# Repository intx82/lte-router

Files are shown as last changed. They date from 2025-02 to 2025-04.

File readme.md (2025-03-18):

# White box DIY LTE router

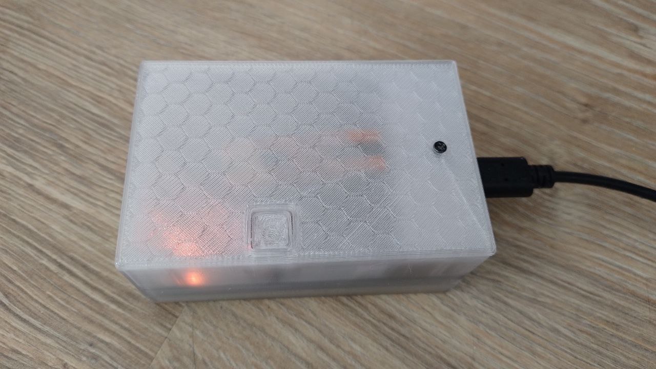
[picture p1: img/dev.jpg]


## 1. Project Description

This project provides a detailed guide to building a DIY battery-powered LTE router, designed with portability and flexibility in mind. The router features two Ethernet ports—one dedicated WAN port for external network connectivity and one LAN port to connect local devices. With built-in LTE connectivity, it ensures reliable internet access even in remote or mobile environments.

The DIY LTE router supports multiple functionalities tailored to diverse applications, such as LTE voice calls and SMS termination through VoIP, secured VPN connectivity, and integrated GPS tracking capabilities. These use cases and their configurations are explained in detail in the subsequent sections of this guide.

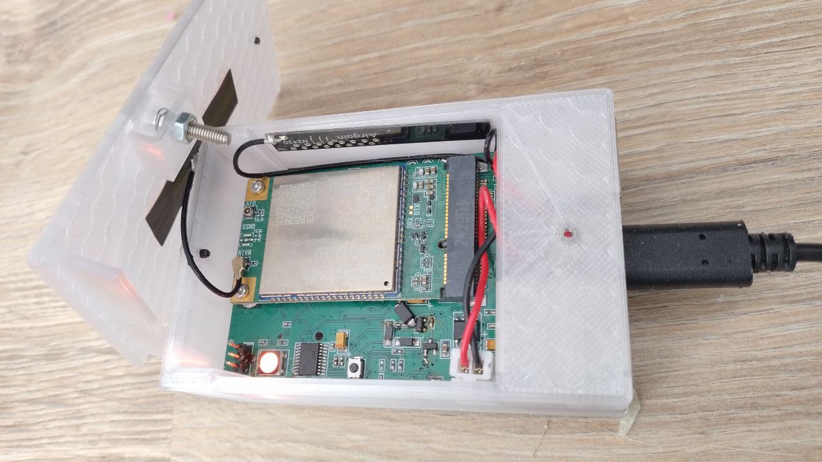
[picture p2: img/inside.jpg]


## 2. Use cases

### 2.1 LTE Voice Calls and SMS Termination via VOIP

The DIY LTE router integrates seamlessly with LTE modems (e.g., Quectel EC25) using the Asterisk VoIP server to enable voice calls and SMS functionality. Calls and SMS messages can be managed using SIP clients (e.g., Zoiper) directly over an IP network.

#### Voice Calls

- **Outgoing Calls:**
    
    - Calls initiated from the SIP client are routed through the LTE modem. The call handling logic is provided in `openwrt/extensions.conf` under the `[zoiper_in]` context.
        
    - Example:
        
        ```
        exten => _X.,1,NoOp("Outgoing call from Zoiper to EC25")
        same => n,Dial(Quectel/ec25_modem/${EXTEN},60)
        same => n,Hangup()
        ```
        
- **Incoming Calls:**
    
    - Calls received by the LTE modem are routed to the configured SIP client.
        
    - Defined in `openwrt/quectel.conf` under `[ec25_modem]` and routed through context `[from-ec25]`:
        
        ```
        exten => s,1,NoOp("Incoming call from EC25")
        same => n,Dial(PJSIP/200)
        same => n,Hangup()
        ```

#### SMS Handling

- **Outgoing SMS:**
    
    - SMS messages can be sent directly from the SIP client using SIP MESSAGE requests.
        
    - Defined under context `[outgoing-sms]`:
        
        ```
        exten => _X!,1,NoOp(Outgoing SIP MESSAGE to send as SMS)
        same => n,QuectelSendSMS(ec25_modem,${EXTEN},${MESSAGE(body)},1440,no,"magicID")
        same => n,Hangup()
        ```
        
- **Incoming SMS:**
    
    - Incoming SMS messages received by the LTE modem are forwarded to the SIP client.
        
    - Managed under `[from-ec25]`:
        
        ```
        exten => sms,1,NoOp(Inbound SMS Received)
        same => n,Set(MESSAGE(body)=${SMS})
        same => n,MessageSend(pjsip:200/200,${CALLERID(num)})
        same => n,HangUp()
        ```

#### Configuration and Permissions

- Configuration files (`extensions.conf`, `PJSIP.conf`, `quectel.conf`, and `modules.conf`) are available in the project's `openwrt` folder.
    
- A SIP client (e.g., Zoiper) should connect to the endpoint defined in `openwrt/PJSIP.conf`.
    
- Basic Asterisk configuration (`/etc/config/asterisk`):

```conf
config asterisk 'general'  
       option enabled '1'  
       option log_stderr '1'  
       option log_stdout '0'  
       option options ''
```

- **Permissions Issues:** 

If there are permission errors accessing `ttyUSB` ports, modify `/etc/init.d/asterisk` as follows: (remove flag -U from command)

```bash
#!/bin/sh /etc/rc.common  
# Copyright (C) 2014 OpenWrt.org  
  
START=99  
  
USE_PROCD=1  
  
#PROCD_DEBUG=1  
  
NAME=asterisk  
COMMAND=/usr/sbin/$NAME  
  
LOGGER="/usr/bin/logger -p daemon.err -s -t $NAME --"  
  
start_service() {  
  
 dbdir=/var/lib/asterisk/astdb  
 logdir=/var/log/asterisk  
 cdrcsvdir=$logdir/cdr-csv  
 rundir=/var/run/asterisk  
 spooldir=/var/spool/asterisk  
 varlibdir=/var/lib/asterisk  
  
 config_load $NAME  
  
 config_get_bool enabled general enabled 0  
 if [ $enabled -eq 0 ]; then  
   $LOGGER service not enabled in /etc/config/$NAME  
   return 1  
 fi  
  
 config_get_bool log_stderr general log_stderr 1  
 config_get_bool log_stdout general log_stdout 0  
  
 config_get options general options  
  
 for i in \  
   "$logdir" \  
   "$cdrcsvdir" \  
   "$rundir" \  
   "$spooldir" \  
   "$varlibdir" \  
   "$dbdir"  
 do  
   if ! [ -e "$i" ]; then  
     mkdir -m 0750 -p "$i"  
     [ -d "$i" ] && chown $NAME:$NAME "$i"  
   fi  
 done  
  
 procd_open_instance  
 procd_set_param command $COMMAND  
 procd_append_param command \  
   $options \  
   -f  
 # forward stderr to logd  
 procd_set_param stderr $log_stderr  
 # same for stdout  
 procd_set_param stdout $log_stdout  
 procd_close_instance  
  
}  
  
reload_service() {  
 procd_send_signal $NAME  
}
```

Configuration files (`extensions.conf`, `PJSIP.conf`, `quectel.conf`, `modules.conf`) are located in the project's `openwrt` folder and should copied to the `/etc/asterisk` folder on the device. 

### 2.2 Secured VPN Gateway

The DIY LTE router supports secure VPN connections using WireGuard and OpenVPN, configured via OpenWrt's command-line interface (CLI). These VPN configurations provide secure, encrypted tunnels for safe internet browsing and remote network access.

#### 2.2.1 WireGuard Setup via UCI

- WireGuard configuration (`/etc/config/network`):
    
    ```
    config interface 'wg0'
      option proto 'wireguard'
      option private_key '<private_key_here>'
      option listen_port '51820'
      list addresses '<VPN-IP>'
    
    config wireguard_wg0
      option public_key '<peer-public-key>'
      option allowed_ips '<VPN_SUBNET>'
      option endpoint '<VPN_SERVER_IP:PORT>'
    ```
    
- Firewall rules in `/etc/config/firewall`:
    
    ```
    config zone
      option name 'wg'
      list network 'wg0'
      option input 'ACCEPT'
      option output 'ACCEPT'
      option forward 'REJECT'
    ```

#### 2.2.2 OpenVPN Setup via CLI

- Place your `.ovpn` file into `/etc/openvpn/`.
    
- Edit `/etc/config/openvpn`:
    
    ```
    config openvpn 'vpnclient'
      option enabled '1'
      option config '/etc/openvpn/<your-config>.ovpn'
    ```
    
- Adjust firewall settings in `/etc/config/firewall`:
    
    ```
    config zone
      option name 'vpn'
      option input 'REJECT'
      option output 'ACCEPT'
      option forward 'REJECT'
      list network 'vpnclient'
    
    config forwarding
      option src 'lan'
      option dest 'vpn'
    ```

#### 2.2.3 LTE Modem MBIM Configuration and Routing

- Reconfigure Quectel EC25 modem to use MBIM mode:
    
    ```
    echo 'at+qcfg="usbnet",1' | socat - /dev/ttyUSB2,crlf
    ```
    
- Configure network interface in `/etc/config/network`:
    ```
    config interface 'wwan'
      option proto 'dhcp'
      option ifname 'eth1'
    ```
- Firewall configuration in `/etc/config/firewall`:
    ```
    config zone
      option name 'wwan'
      list network 'wwan'
      option input 'REJECT'
      option output 'ACCEPT'
      option forward 'REJECT'
      option masq '1'
    
    config forwarding
      option src 'lan'
      option dest 'wwan'
    ```

#### 2.2.4 Routing All Traffic through VPN via WWAN (`eth1`)

- Configure default routing to forward all traffic through VPN interface linked with the WWAN (`eth1`):
    ```
    uci set network.lan.gateway='<VPN_GATEWAY_IP>'
    uci set network.lan.dns='<VPN_DNS_IP>'
    uci commit network
    /etc/init.d/network restart
    ```
- Ensure firewall rules allow forwarding from LAN to VPN:
    ```
    config forwarding
      option src 'lan'
      option dest 'vpn'
    ```
This setup ensures that all network traffic from your local devices is securely tunneled through your VPN connection using the WWAN (`eth1`) interface.

### 2.3 Network Storage with MicroSD and NFS Server

The DIY LTE router includes onboard storage using a MicroSD card and features an integrated NFS-kernel-server for network file sharing.

#### Mounting the MicroSD Card

Use the following commands to detect and mount the MicroSD card automatically:

```
block detect | uci import fstab
uci commit
/etc/init.d/fstab enable
/etc/init.d/fstab start
```

Example UCI configuration (`/etc/config/fstab`):

```
config global
        option anon_swap '0'
        option anon_mount '0'
        option auto_swap '1'
        option auto_mount '1'
        option delay_root '5'
        option check_fs '0'

config mount
        option target '/mnt/mmcblk0p1'
        option uuid '<UUID_generated_by_block_detect>'
        option enabled '1'
```

Verify mounted storage with:

```
df -h
```

#### Configuring the NFS-kernel-server

- Configure exports in `/etc/exports`:

```
/mnt/mmcblk0p1  *(rw,sync,no_root_squash,no_subtree_check)
```

- Enable and start NFS server:

```
/etc/init.d/nfsd enable
/etc/init.d/nfsd start
```

- Adjust firewall rules to allow NFS:

```
uci add firewall rule
uci set firewall.@rule[-1].src='lan'
uci set firewall.@rule[-1].dest_port='2049'
uci set firewall.@rule[-1].proto='tcpudp'
uci set firewall.@rule[-1].target='ACCEPT'
uci commit firewall
/etc/init.d/firewall restart
```

This setup allows your router to function as a robust network-attached storage solution accessible to clients on your local network.

## 3. Assembly

### 3.1 Hardware

#### 3.1.1 STL files and box

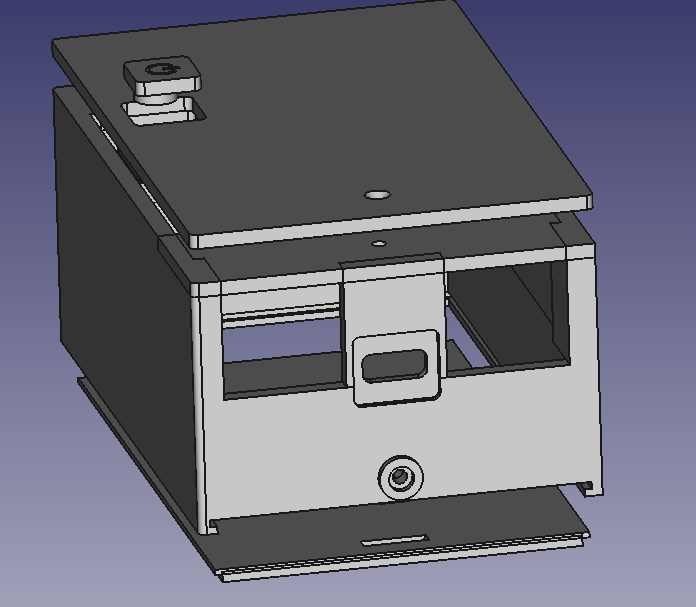
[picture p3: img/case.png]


use files located in `3d/stl`. To modify it, use 'Freecad'

#### 3.1.2 PCB

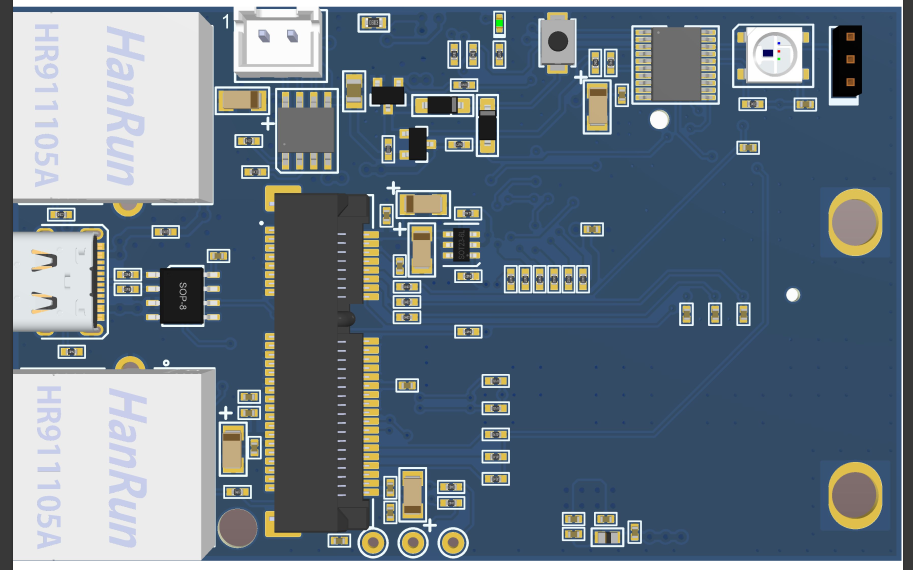
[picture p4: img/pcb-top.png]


Use altium project `pcb/lte-router_V3_ARCHIVE/lte-router_V3_DIV/lte-router_V3.PrjPcb`

Schematic and PCB documentation available in PDF file here: [`pcb/lte-router_V3_ARCHIVE/lte-router_V3_GENERATED/DOC/lte-router_V3_DOC.PDF`](https://github.com/intx82/lte-router/blob/master/pcb/lte-router_V3_ARCHIVE/lte-router_V3_GENERATED/DOC/lte-router_V3_DOC.PDF)

**Additional thanks to Michael who done this work**

### 3.2 Software

#### 3.2.1 Power Managment IC (pmic) firmware

For `PMIC` has been used 'CH32V003F4P6' Risc-V CPU

To build it, be sure that you have installed `riscv64-gnu-linux-gcc` and just run `make -C pmic/fw`.

#### 3.2.2 Openwrt 

- Use official 'Openwrt' repository and checkout to the '09e32bf62a7dc0f252605720910b02ed26994263' commit, follow the openwrt build instructions
- Then put `openwrt/config` file to the openwrt folder as .config
- After copy contents of `pmic/tool` to the `package/utils/pmicctrl/`
- Apply all patches from `openwrt` folder
- `make`
- Take a firmware from `bin/targets/ramips/mt76x8` 
- Upload it to the device using `scp` - `scp openwrt-snapshot-r28739+2-69890e16b3-ramips-mt76x8-hilink_hlk-7688a-squashfs-sysupgrade.bin root@192.168.1.1:/tmp` or if this is stock HLK-7688 - `scp openwrt-snapshot-r28466-6881b48dc6-ramips-mt76x8-hilink_hlk-7688a-squashfs-sysupgrade.bin root@192.168.16.254:/tmp`. Password to stock module Wi-Fi is '12345678'
- Flash it with `sysupgrade -n /tmp/openwrt-snapshot-r28739+2-69890e16b3-ramips-mt76x8-hilink_hlk-7688a-squashfs-sysupgrade.bin`

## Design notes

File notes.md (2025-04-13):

## GDB CH32V003

```
set architecture riscv:rv32
target extended-remote /dev/ttyACM0
load main.elf 0
```

## tasks V1->V2

- [x] C6 to 0603 or type-a tantal
- [x] c18 - 0402
- [x] vt3 (ap2301b) wrong case, sot23-6 instead of sot23-3
- [x] power switch latch change to ch32v003
	- [x] PD3 - enable (to base vt2)
	- [x] PD4 - button
	- [x] PC1 - I2C-SDA (25 pin hlk-7688)
	- [x] PC2 - I2C-SCL (24 pin hlk-7688)
	- [x] PA2 - voltage divider 470k/470k to battery (before tp4056)
	- [x] PC6 - WS2812
	- [x] PD1 - SWD (SWIO)
	- [x] wwan/wpan/wlan led - to one pin
	- [x] power tp4056 - one pin
	- [x] charge tp4056 - one pin
- [x] sim card set connector with loading from top, not from side
- [x] add 10k pull-up for sd-card (@see link-it 7688 schematic)
- [x] add zero resistor to avoid dw01

## Notes

```
socat /dev/ttyUSB2,b115200,raw,echo=0,crnl -

```

# Asterisks termination 
## quectel.conf

```
[general]  

[ec25_modem]  
device=/dev/ttyUSB1      ; or whichever your voice port is  
context=from-ec25        ; context for incoming calls from EC25  
audio=/dev/ttyUSB1       ; in some builds you might configure separate audio channels  
data=/dev/ttyUSB2        ; optional if used for data  
autostart=yes  
```

## PJSIP.conf

```
[transport-udp]  
type=transport  
protocol=udp  
bind=0.0.0.0  

[200]  
type=endpoint  
transport=transport-udp  
context=zoiper_in  
disallow=all  
allow=ulaw  
auth=200  
aors=200  
message_context=outgoing-sms  
  
[200]  
type=auth  
auth_type=userpass  
username=200  
password=200  
  
[200]  
type=aor  
max_contacts=1  
```

## extension.conf

```
[zoiper_in]  
; When Zoiper dials an external number, send it out through the EC25  
exten => _X.,1,NoOp("Outgoing call from Zoiper to EC25")  
same => n,Dial(Quectel/ec25_modem/${EXTEN},60)  
same => n,Hangup()  
  
[outgoing-sms]  
exten => _X!,1,NoOp(Outgoing SIP MESSAGE to send as SMS)  
same => n,Verbose(1,"Outbound SMS to: ${EXTEN} -> ${MESSAGE(body)}")  
same => n,QuectelSendSMS(ec25_modem,${EXTEN},${MESSAGE(body)},1440,no,"magicID")  
same => n,NoOp("SMS send status: ${QUECTELSENDSMS_STATUS}")  
same => n,Hangup()  
  
[from-ec25]  
; For calls that come in from the modem  
exten => s,1,NoOp("Incoming call from EC25")  
same => n,Verbose(2, "Incoming dial ${CALLERID(num)})  
same => n,Dial(PJSIP/200)  
same => n,Hangup()  
  
exten => sms,1,NoOp(Inbound SMS Received)  
same => n,Set(MESSAGE(body)=${SMS})  
same => n,Set(MESSAGE(from)=sip:${CALLERID(num)}@domain.invalid)  
same => n,Set(MESSAGE(to)=sip:200@domain.invalid)    
same => n,MessageSend(pjsip:200/200,${CALLERID(num)})  
same => n,Verbose(2, "Send status is ${SMS} ${CALLERID(num)})  
same => n,HangUp()
```

### modules.conf

root@OpenWrt:~# cat /etc/asterisk/modules.conf    
```
[modules]  
autoload=yes  
  
noload = chan_alsa.so  
noload = res_hep.so  
noload = res_hep_pjsip.so  
noload = res_hep_rtcp.so  
noload = chan_sip.so  
noload = app_voicemail_imap.so  
noload = app_voicemail_odbc.so  
  
load => chan_quectel.so
```

----

# PMIC register map

| # | type | name | Description |
| --- | --- | --- | --- |
| 4..7 | uint32 | tm | Internal time in ms |
| 8..11  | uint32 | led-color | Led Color GRB,  if data\[11\] > 0 then update_led() |
| 12..13 | uint16 | adc-val | Battery value |
| 14 | uint8  | in-state  | Bits:<br>0 - TP4056 - Charge<br>1 - TP4056 - Standby<br>2 - LTE leds state (wwan/wpan/wlan)<br>3 - Power button state<br>4 - Battery low indication (~3.5v) |
| 31 | uint8  | shutdown  | if write 0xff -> then shutdown |

----------

# I2C shortcuts

```
i2cdetect -y 0 # PMIC should be visible as device with address 9
i2cget -y 0 9 0 i 32 # get all pmic registers

i2cset -y 0 9 8 0xff b # set red led to 0xff
i2cset -y 0 9 11 0xff b # apply led color

i2cset -y 0 9 8 0x10 0x20 0x30 0x01 i  # update the color of the led in one command
i2cset -y 0 9 8 0x0 0x0 0x0 0x01 i  # update the color of the led in one command

i2cset -y 0 9 31 0xff b  # shutdown the device
```

-----

# Wireless config

```
config wifi-device 'radio0'      
       option type 'mac80211'  
       option path 'platform/10300000.wmac'  
       option band '2g'     
       option channel '1'  
       option htmode 'HT20'  
       option disabled '0'  
  
config wifi-iface 'default_radio0'  
       option device 'radio0'  
       option network 'lan'  
       option mode 'ap'  
       option ssid 'OpenWrt'  
       option encryption 'none'
```

For WPA encryption change `config wifi-iface 'default_radio0'` to:

```
config wifi-iface 'default_radio0'
        option device 'radio0'
        option network 'lan'
        option mode 'ap'
        option ssid '[access-point]'
        option encryption 'psk2'
        option key '[das-password]'
```

# Control LTE module power

```
echo 'out' > /sys/class/gpio/lte_sw/direction
echo 1 > /sys/class/gpio/lte_sw/value # enable
echo 0 > /sys/class/gpio/lte_sw/value # disable
```

## EC200 workaround

To set right modem mode to use it as WWAN:

```
echo "at+qnetdevctl=3,1,1" | socat - /dev/ttyUSB2,crlf
```

# PMICCTRL UBUS  shortcuts

```bash
ubus listen
ubus call pmic set_led '{"r":128, "g":0, "b": 16}'
ubus call pmic shutdown
```

## BlockD

To mount flash use next thing:

```bash
block detect | uci import fstab
uci commit
```

## Enable wifi

```
uci set wireless.radio0.disabled=0
```

## Change EC25 USB mode

```
at+qcfg="usbnet",1
```

/etc/config/network

```
config interface 'wwan'  
       option proto 'dhcp'  
       option ifname 'eth1'
```

## PCB V2->V3

- [x] Ethernet led connect to VCC instead of GND
- [x] Connect modem thru the diode to the VBAT (after Mosfet)
- [x] Change bc847 to bss138 and add to the Gate-GND resistor 100k
- [x] separate resistors to CC1 / CC2  (for each pin own - 5.1k)

## Wireguard config

/etc/config/firewall:

```
  
config zone  
       option name 'wg'  
       list network 'wg0'  
       option input 'ACCEPT'  
       option output 'ACCEPT'  
       option forward 'REJECT'  
  
config rule  
       option name 'Allow-SSH-from-WG'  
       option src 'wg'  
       option target 'ACCEPT'  
       option dest_port '22'  
       option proto 'tcp'  
  
config rule  
       option name             Allow-asterisk  
       option src              'wg'  
       option proto            udp  
       option dest_port        5060  
       option target           ACCEPT  
       option family           ipv4
```

/etc/config/network

```
config interface 'wg0'  
       option proto 'wireguard'  
       option private_key 'BASE64='  
       option listen_port '51820'  
       list addresses 'VPN-IP'  
  
config wireguard_wg0  
       option public_key 'BASE64='  
       option allowed_ips 'VPN-SUBNET/24'  
       option endpoint_host 'SRV-IP'  
       option endpoint_port 'SRV-PORT'  
       option persistent_keepalive '25'
```

## Traffic count

`AT+QGDCNT?`  - Packet Data Counter
`AT+QNWINFO` - Information about network

# Internet over SLIP

device:

```plantuml
device@10.42.0.2 -> host@10.42.0.1
```

Device sl0.up script:

```bash
#!/bin/sh  
  
stty -F /dev/ttyS0 -crtscts speed 230400  
sleep 1  
slattach -L /dev/ttyS0 &  
sleep 1  
ifconfig sl0 10.42.0.2 pointopoint 10.42.0.1 up  
ifconfig sl0 mtu 1536 up  
# route add default gw 10.42.0.1
```

Host sl0.up script:

```bash
#!/bin/bash  
  
stty -F /dev/ttyUSB0 speed 230400 -crtscts  
slattach -L -d /dev/ttyUSB0  &  
sleep 1  
ifconfig sl0 10.42.0.1 pointtopoint 10.42.0.2 up  
ifconfig sl0 mtu 1536 up  
route add default gw 10.42.0.2  # Use this if you planned to share internet throught SLIP interface
```

Check files `host.sl0.up` `dev.sl0.up` in openwrt folder
If you planned to share internet connection throught SLIP, then add exceptions to the firewall:

`/etc/config/firewall`: ('+' - means added)
```
config zone  
       option name             lan  
       list   network          'lan'  
+       list   network          'slip'  
       option input            ACCEPT  
       option output           ACCEPT  
       option forward          ACCEPT  
  
config zone  
       option name             wan  
       list   network          'wan'  
       list   network          'wan6'  
+       list   network          'wwan'  
       option input            REJECT  
       option output           ACCEPT  
       option forward          REJECT  
       option masq             1  
       option mtu_fix          1
```

`/etc/config/network`:

```
config device  
       option name 'sl0'  
  
config interface 'slip'  
       option device 'sl0'

config interface 'wwan'  
       option proto 'dhcp'  
       option ifname 'eth1'
```

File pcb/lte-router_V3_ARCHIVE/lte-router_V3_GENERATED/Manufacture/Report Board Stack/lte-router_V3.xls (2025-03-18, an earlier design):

Board Stack Report
Stack Up |  | Layer Stack
Layer | Board Layer Stack | Name | Material | Thickness | Constant
1 |  | Top Paste
2 |  | Top Overlay
3 |  | Top Solder | Solder Resist | 0.010mm | 3.5
4 |  | Top Layer | Copper | 0.036mm
5 |  | Dielectric1 | FR-4 | 0.550mm | 4.2
6 |  | Inner Layer 2 | Copper | 0.036mm
7 |  | Dielectric 4 |  | 0.200mm | 4.2
8 |  | Inner Layer 3 | Copper | 0.036mm
9 |  | Dielectric2 | FR-4 | 0.550mm | 4.2
10 |  | Bottom Layer | Copper | 0.036mm
11 |  | Bottom Solder | Solder Resist | 0.010mm | 3.5
12 |  | Bottom Overlay
13 |  | Bottom Paste
 | Height : 1.463mm

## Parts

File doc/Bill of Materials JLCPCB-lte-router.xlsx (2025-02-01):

Description | Designator | Footprint | JLCPCB Part #（optional）
Battery Holder (Open) 18650 1 Cell SMD (SMT) Tab | BAT1 | 1042P | C6038009
CAP CER 10nF ±10% 50V X7R 0402 | C1, C11 | C_0402 | C15195
CAP TANT 10UF 10% 16V 1206 | C2, C3, C7, C10, C14 | TANT_CAP_A | C110055
CAP CER 10PF ±5% 50V C0G/NP0 0402 | C4, C5, C12, C13, C22, C23, C24, C26 | C_0402 | C76946
CAP CER 1UF ±10% 25V X7R 0603 | C6 | C_0603 | C29936
CAP CER 4.7UF ±10% 10V X7R 0603 | C8, C20, C21 | C_0402 | C913474
CAP CER 10UF ±10% 10V X6S 0603 | C9, C15, C17 | C_0402 | C385036
CAP CER 47PF ±5% 50V C0G/NP0 0402 | C16 | C_0402 | C84706
CAP CER 10nF ±10% 50V X7R 0603 | C18, C19, C25 | C_0603 | C1589
5A 1 Horizontal attachment 6P Female -25℃~+85℃ Type-C SMD USB Connectors ROHS | J1 | USB-TYPE-C-006 | C2927026
RJ45Receptacle 1 WithLED Plugin Ethernet Connectors / Modular Connectors (RJ45 RJ11) ROHS | J2, J3 | HR911105A | C12074
-20℃~+85℃ 1.6mm Gold Card Slot MicroSD card (TF card) Flip type SMD SD Card / Memory Card Connector ROHS | J4 | TF-014-H16 | C2874208
Jamper 2 pin | JP1, JP2 | JUMP_2 | C2931354
Kontrol Point c2.0mm_h1.0mm | KP1, KP2 | KP_c2_h1
3.6A 1.5uH ±20% 5.3A SMD,4x4mm Power Inductors ROHS | L1 | SMD4x4 | C167867
FERRITE BEAD 220 OHM 0603 1LN | L2 | L_0603 | C113025
LED GREEN CLEAR 2SMD | LED1, LED3, LED5 | LED_0402_G | C2852592
LED RED CLEAR CHIP SMD | LED2, LED4 | LED_0402_R | C2852592
LED YELLOW CLEAR CHIP SMD | LED6 | LED_0402_Y | C5875733
Any Res 1206 | R1 | R_1206
RES 100K OHM 1% 1/16W 0402 | R2, R7, R12, R13, R22 | R_0402 | C60490
RES 10K OHM 1% 1/16W 0402 | R3, R8 | R_0402 | C60490
Any Res 0603 | R4, R5, R6 | R_0603
RES 1M OHM 5% 1/16W 0402 | R9 | R_0402 | C384387
RES 330 OHM 5% 1/16W 0402 | R10, R18, R19, R20 | R_0402 | C168264
RES 1K OHM 1% 1/16W 0402 | R11, R14 | R_0402 | C163815
RES 47 OHM 5% 1/16W 0402 | R15, R16, R17 | R_0402 | C170414
RES 453K OHM 1% 1/16W 0402 | R21 | R_0402 | C137978
RES 0 OHM JUMPER 1/16W 0402 | R23, R24, R25, R26, R27 | R_0402 | C60485
Plug-in Card Slot MiniSIM card SMD SIM Card Connectors ROHS | SIM1 | HYC90-SIM06-180 | C645506
SWITCH TACTILE SPST-NO 0.02A 15V | SW1, SW2 | PTS525 | C221856
SOP-8 USB2.0 Converter ROHS | U1 | SOP-8 | C2977777
4V~6V Li-Ion/Polymer 1 1A ESOP-8 Battery Management | U2 | ESOP-8 | C382139
Step-down type 2A 2.7V~5.5V SOT-23-5 DC-DC Converters ROHS | U3 | SOT-23-5 | C78988
DIODE SCHOTTKY 60V 3A SMA | VD1 | SMA | C3014012
TRANS NPN 45V 0.1A SOT23-3 | VT1, VT4 | SOT-23-3 | C94393
20V 2A 130mΩ@4.5V,2A 750mW 950mV@250uA 1 Piece P-Channel SOT-23 MOSFETs ROHS | VT2 | SOT-23-6 | C2763847
20V 3A 23mΩ@4.5V,3A 800mW 750mV@250uA 1PCSNChannel+1PCSPChannel SOT-23-6 MOSFETs ROHS | VT3 | SOT-23-6L | C2849575
CONN PCI EXP MIN FML 52POS 0.031 | X1 | 17758382 | C91936
20dBm MT7688AN Chip WiFi Modules | X2 | 7688A | C209919

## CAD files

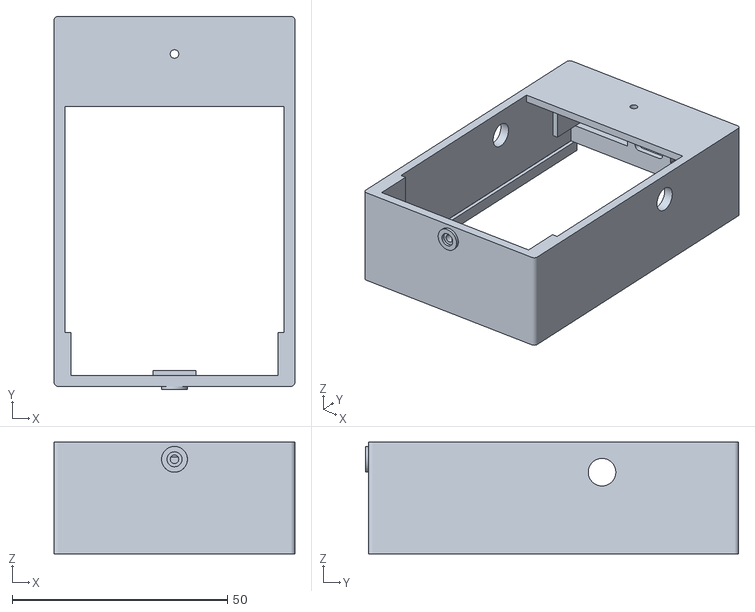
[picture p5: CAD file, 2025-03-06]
3d/stl/lte-router-main-sma.stl
56.0 x 86.8 x 26.0

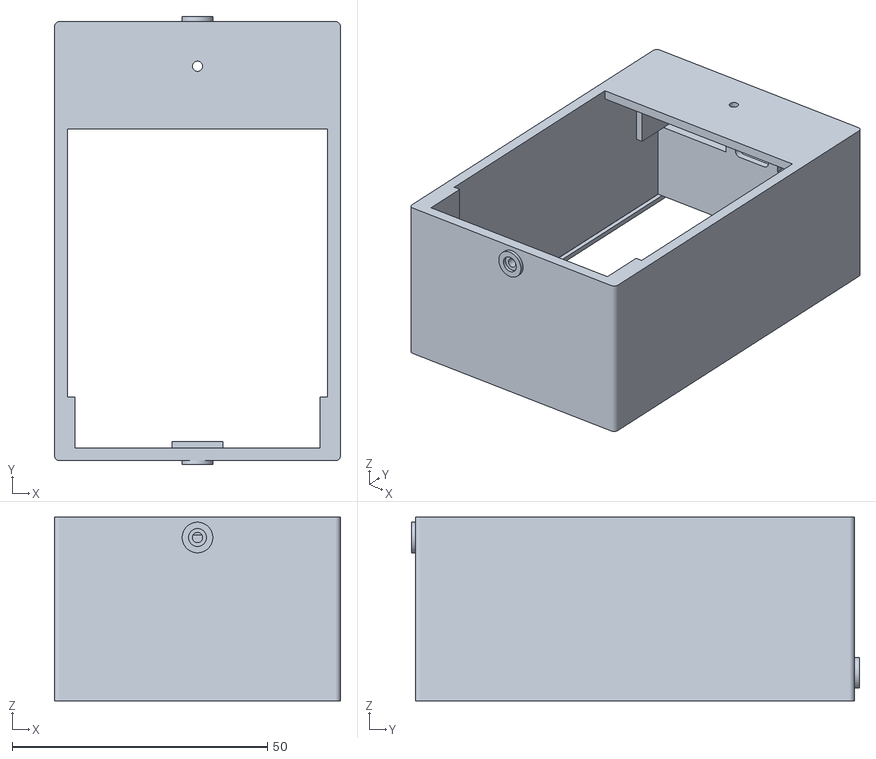
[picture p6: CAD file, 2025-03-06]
3d/stl/lte-router-table-v2-main.stl
56.0 x 87.8 x 36.0

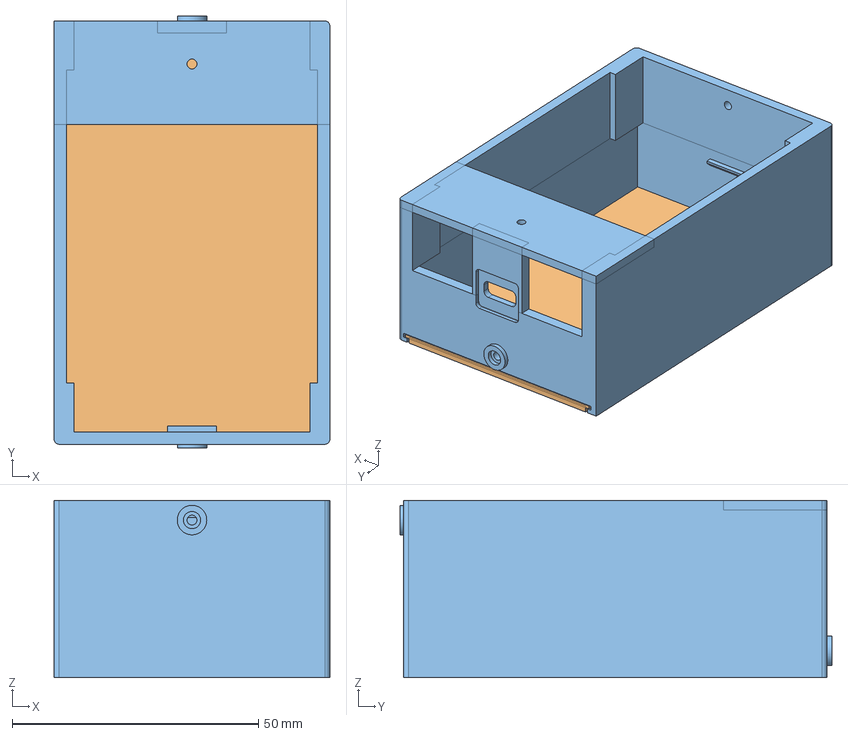
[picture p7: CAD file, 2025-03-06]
3d/lte-router-table-v2.FCStd
56.0 x 87.8 x 36.0 mm
lock
bottom
main

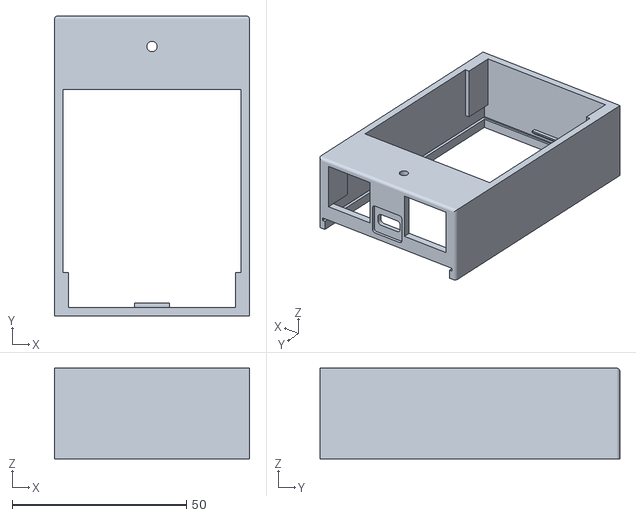
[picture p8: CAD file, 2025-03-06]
3d/stl/lte-router-table-Fillet.stl
56.0 x 86.0 x 26.0

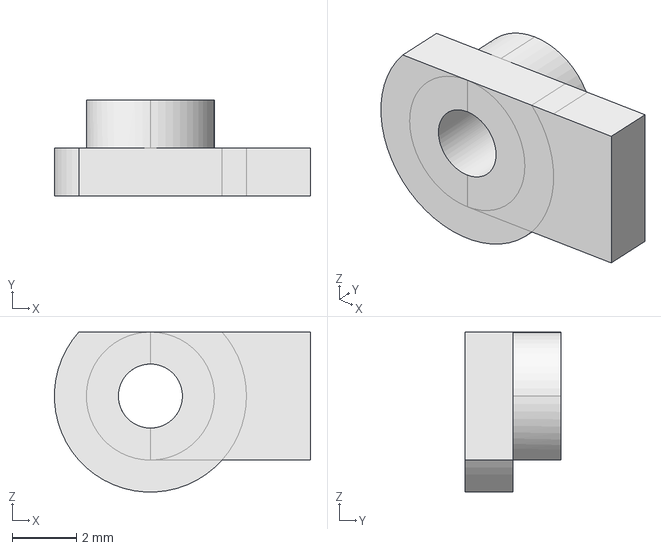
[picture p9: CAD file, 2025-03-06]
3d/lte-router-table.FCStd
8.00 x 3.00 x 5.00 mm

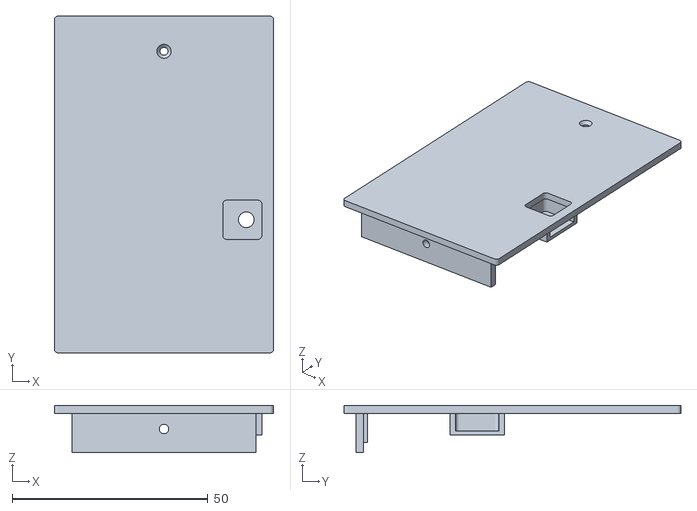
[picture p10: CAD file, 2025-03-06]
3d/stl/lte-router-top.stl
56.0 x 86.0 x 12.0

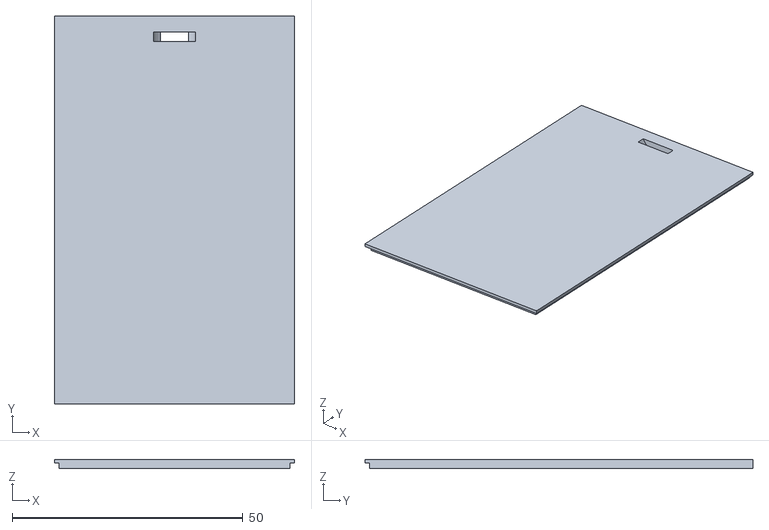
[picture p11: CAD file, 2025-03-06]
3d/stl/lte-router-table-v2-bottom.stl
52.0 x 84.0 x 1.88

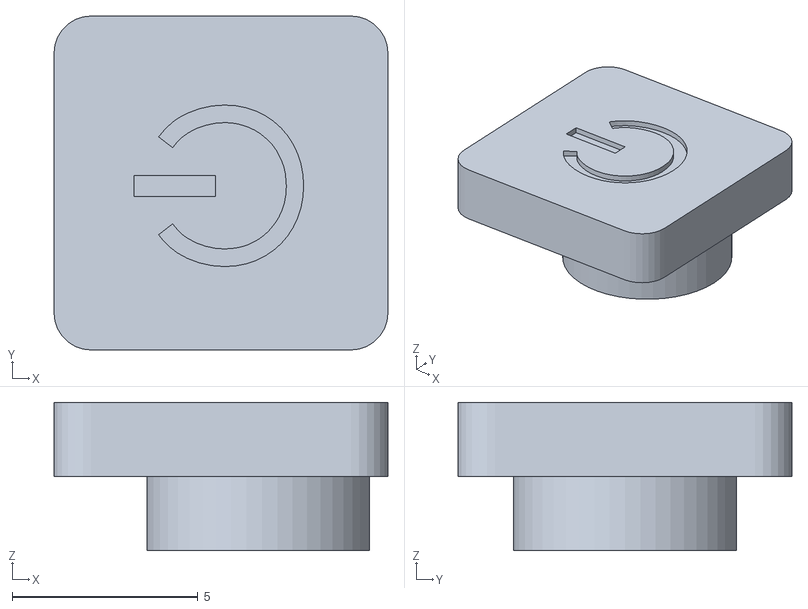
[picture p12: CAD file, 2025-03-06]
3d/stl/lte-router-btn.stl
9.00 x 9.00 x 4.00

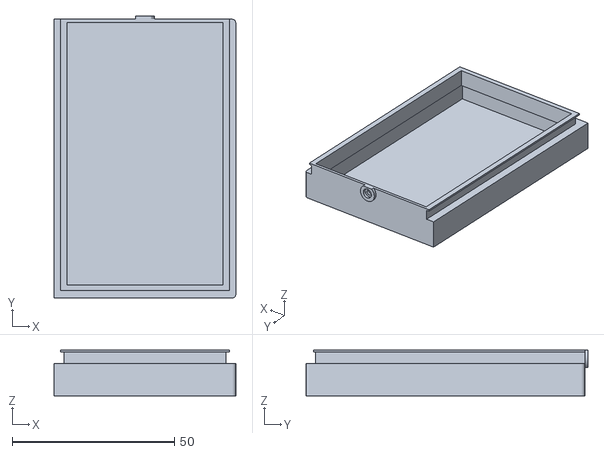
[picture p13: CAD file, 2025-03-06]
3d/stl/lte-router-bat.stl
56.0 x 87.0 x 14.1

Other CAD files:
3d/stl/lte-router-main.stl
3d/lte-router-table-outdoor-ant.FCStd
3d/stl/lte-router-table-lock.stl

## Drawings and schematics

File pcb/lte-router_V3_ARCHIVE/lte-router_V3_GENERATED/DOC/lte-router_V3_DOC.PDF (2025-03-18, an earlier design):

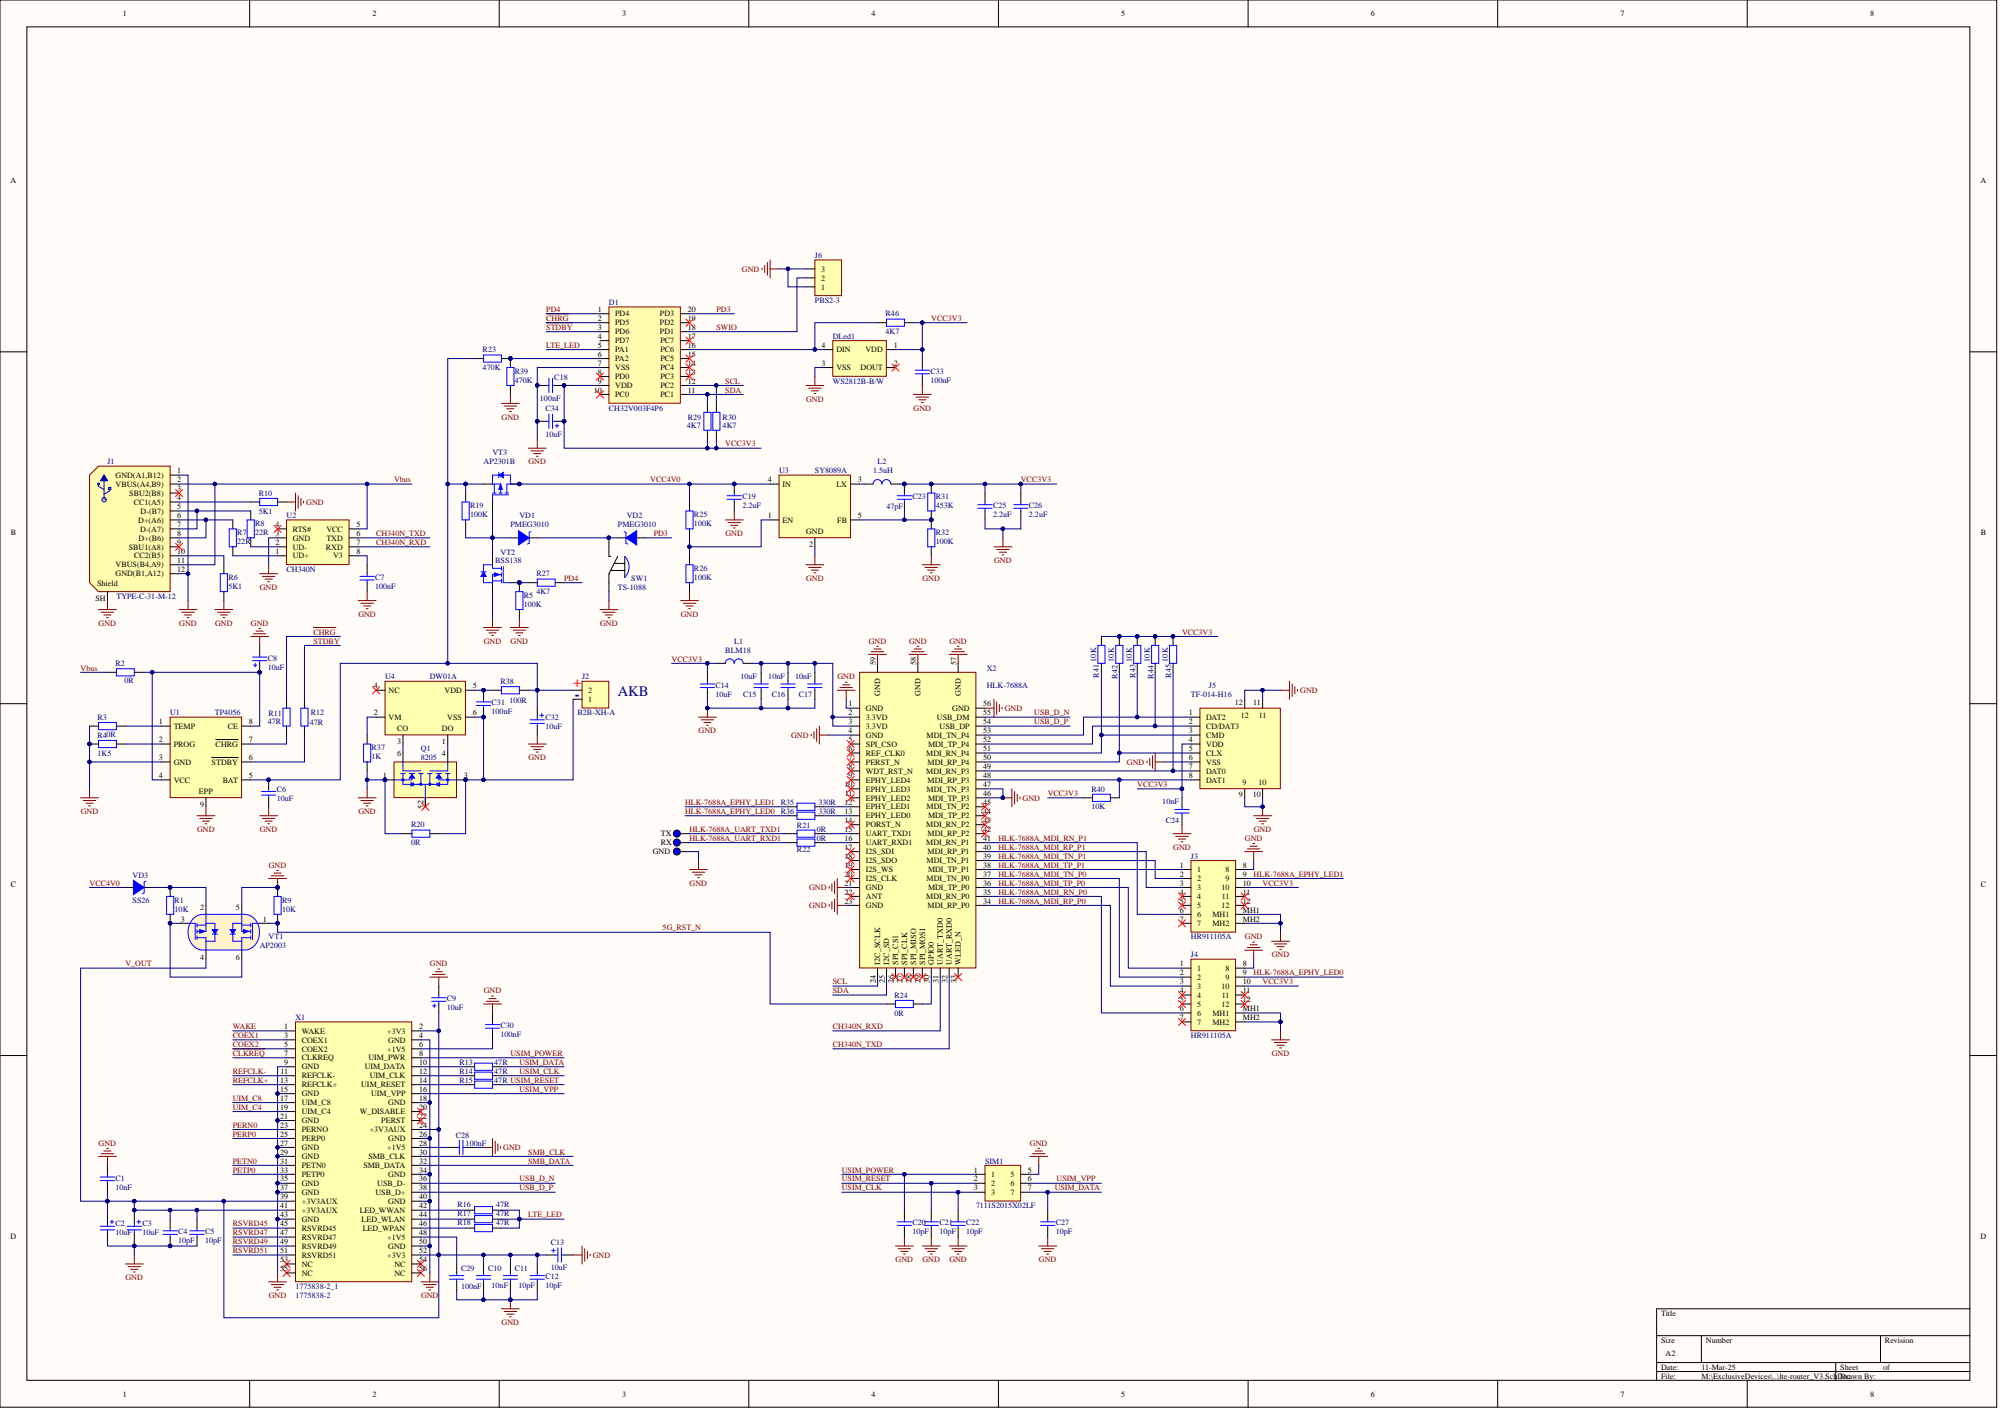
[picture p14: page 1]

WDT_RST_N 8 | | DAT0 7

EPHY_LED3 10 | VCC3V3

I2S_SDI 17 | HLK-7688A_MDI_RP_P1
I2S_SDO 18 | HLK-7688A_MDI_TN_P1

I2S_CLK 20 | HLK-7688A_MDI_TN_P0 | 2 2
GND 21 | HLK-7688A_MDI_TP_P0 | 3 3
ANT 22 | HLK-7688A_MDI_RN_P0 | 4 4
GND 23 | HLK-7688A_MDI_RP_P0 | 5 5

SCL | 3 3
SDA | 4 4

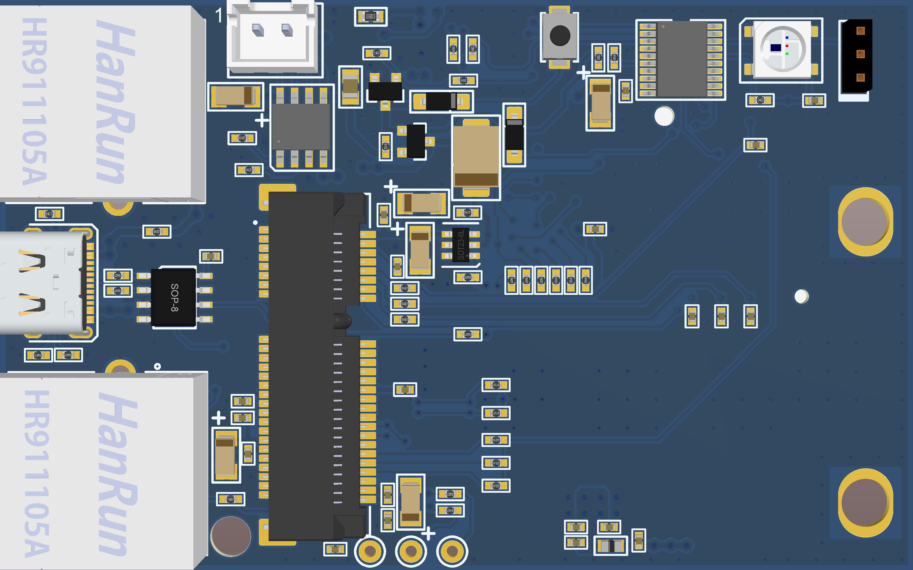
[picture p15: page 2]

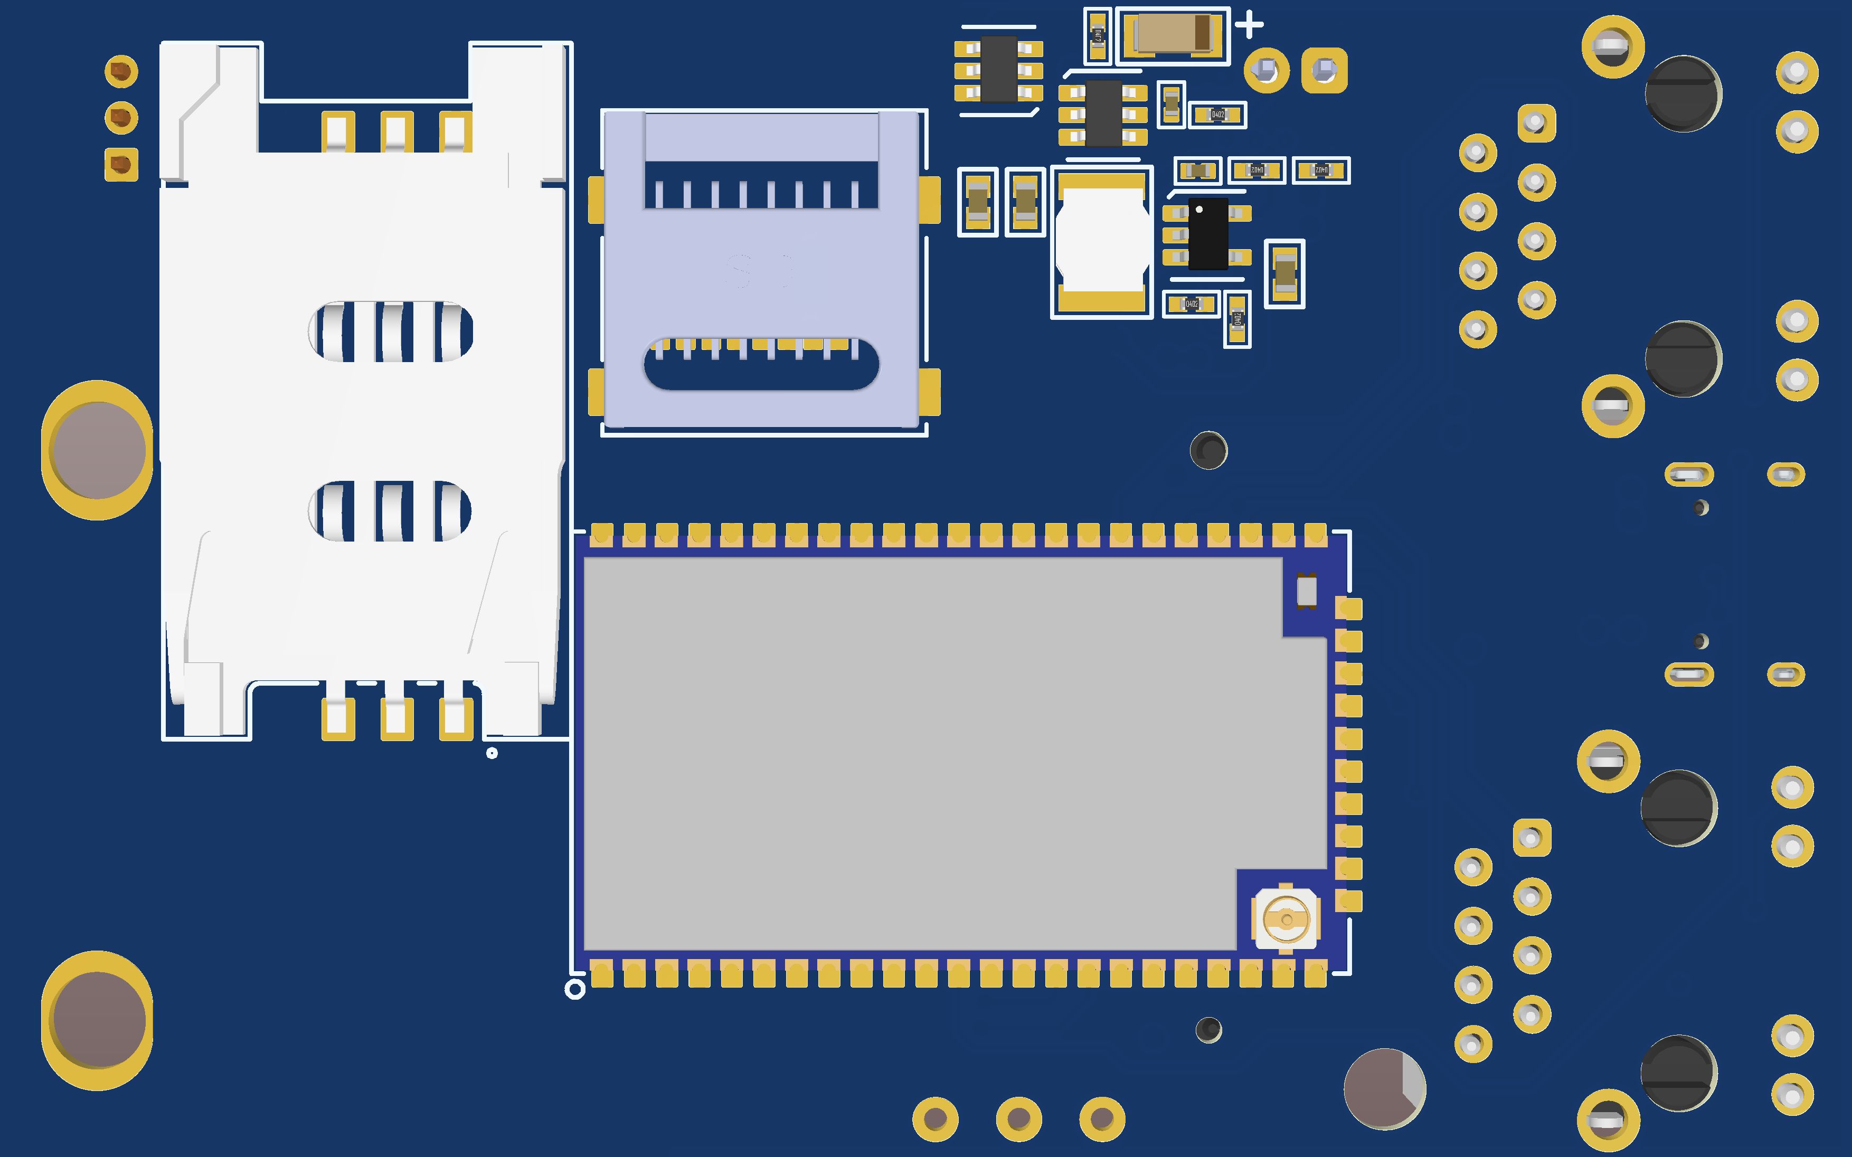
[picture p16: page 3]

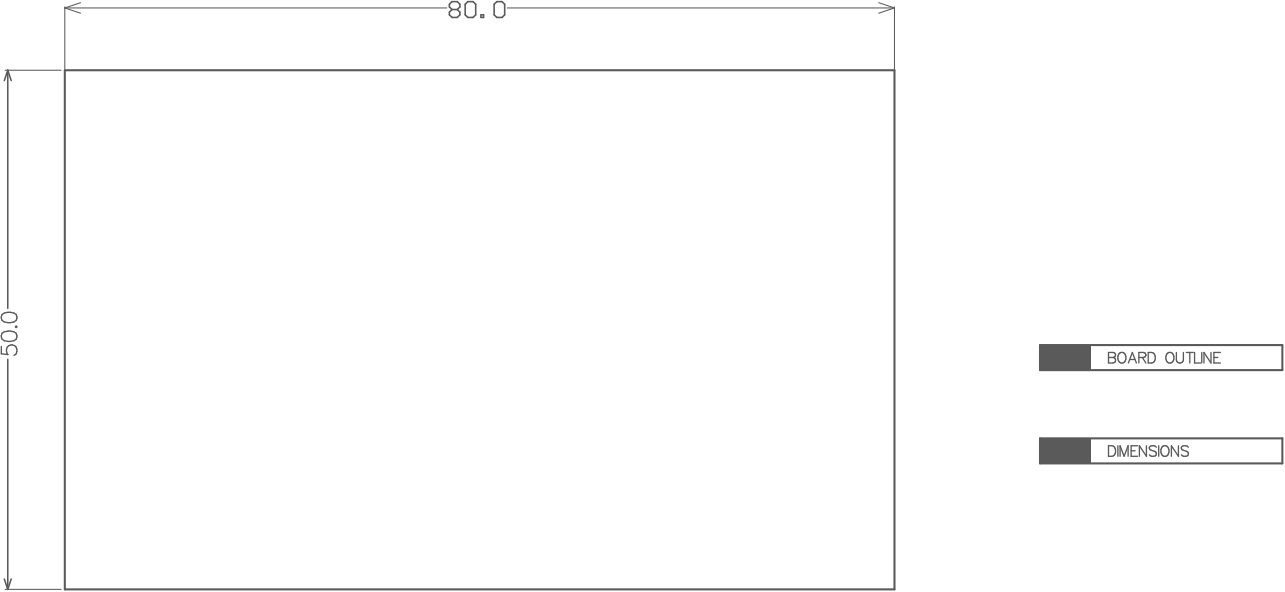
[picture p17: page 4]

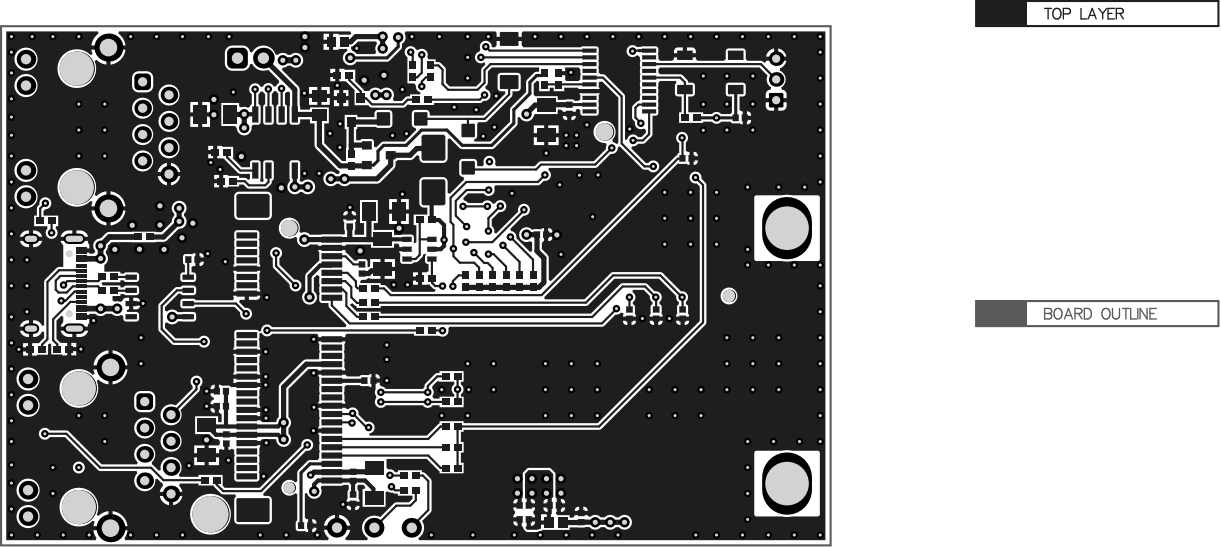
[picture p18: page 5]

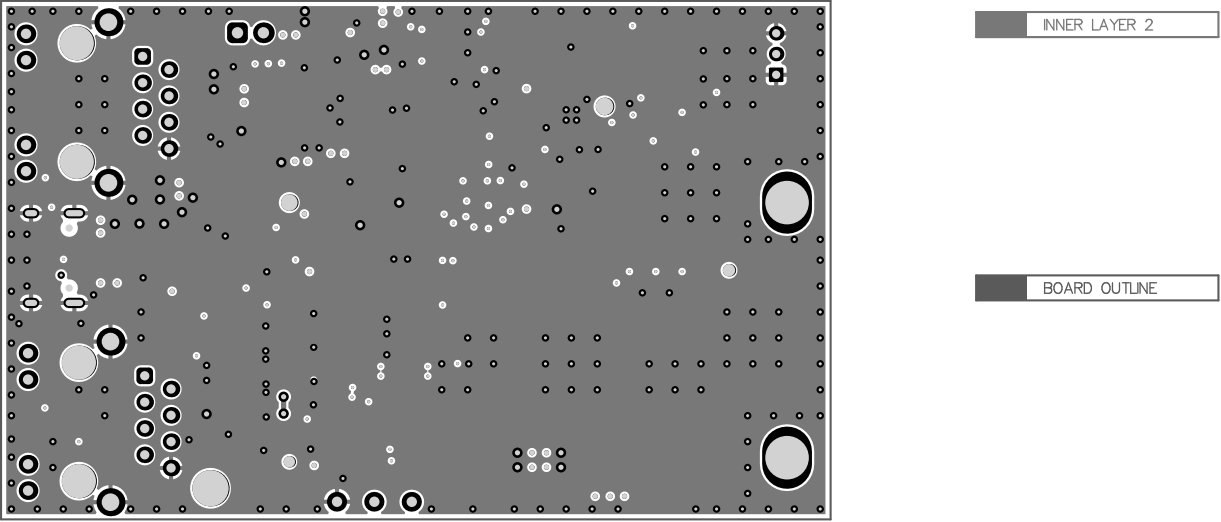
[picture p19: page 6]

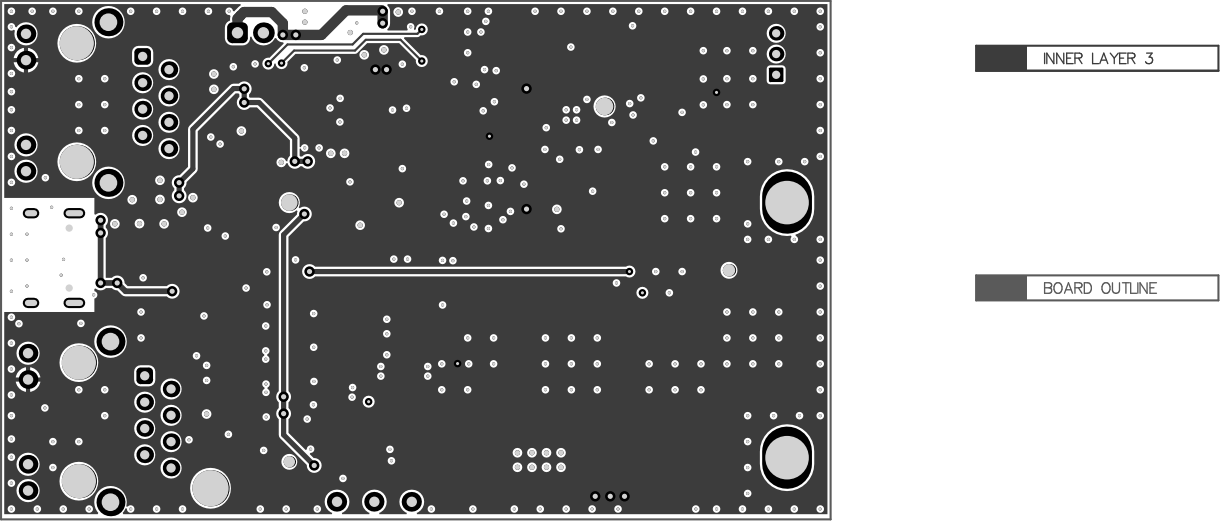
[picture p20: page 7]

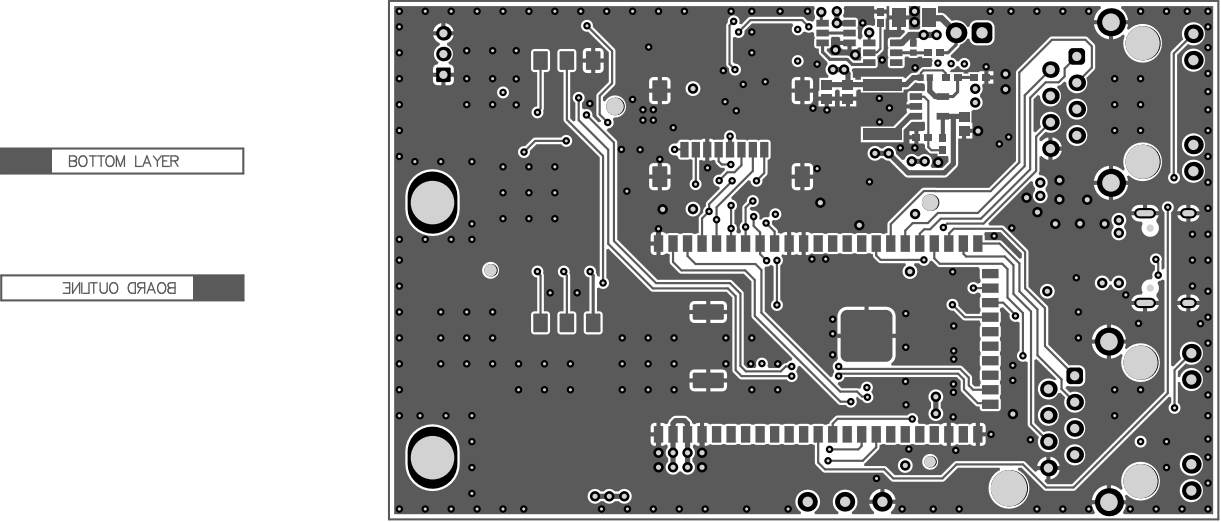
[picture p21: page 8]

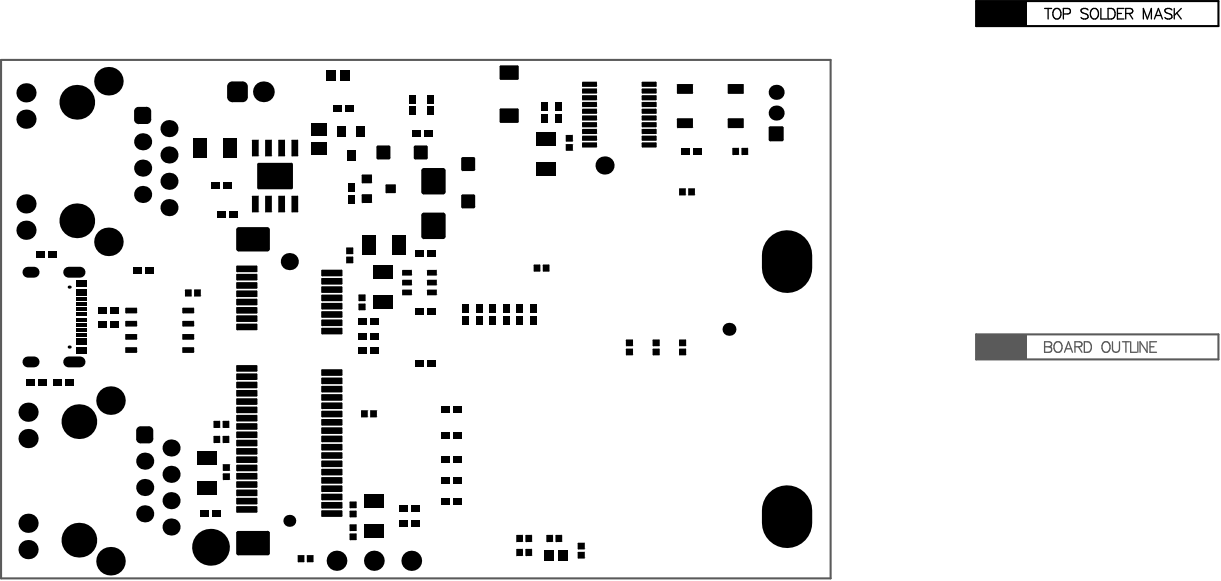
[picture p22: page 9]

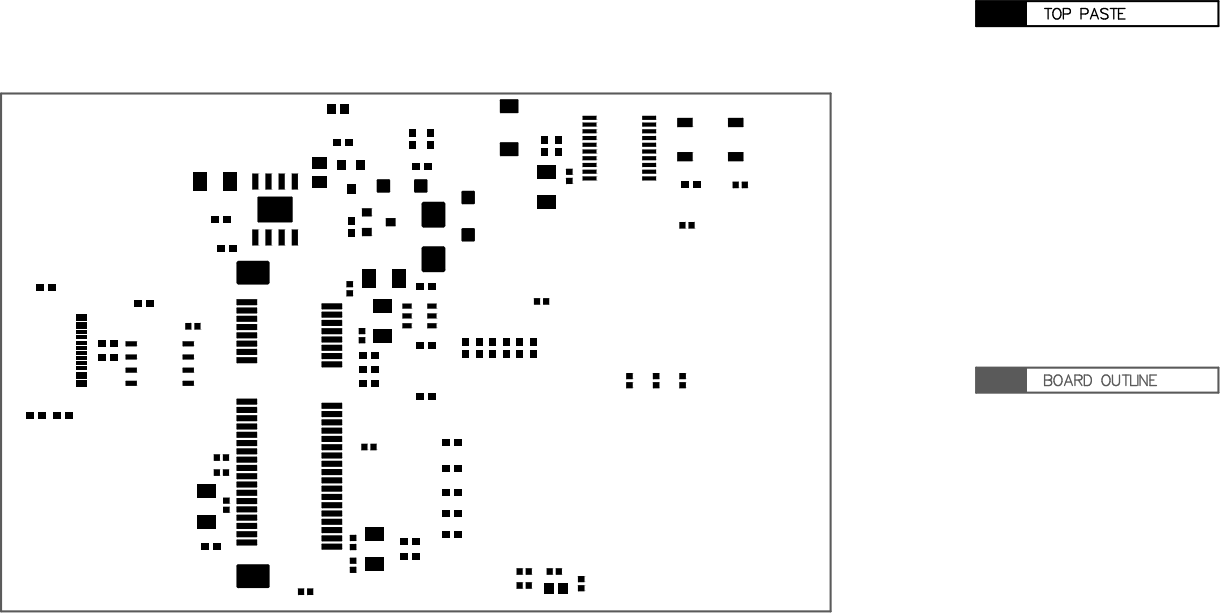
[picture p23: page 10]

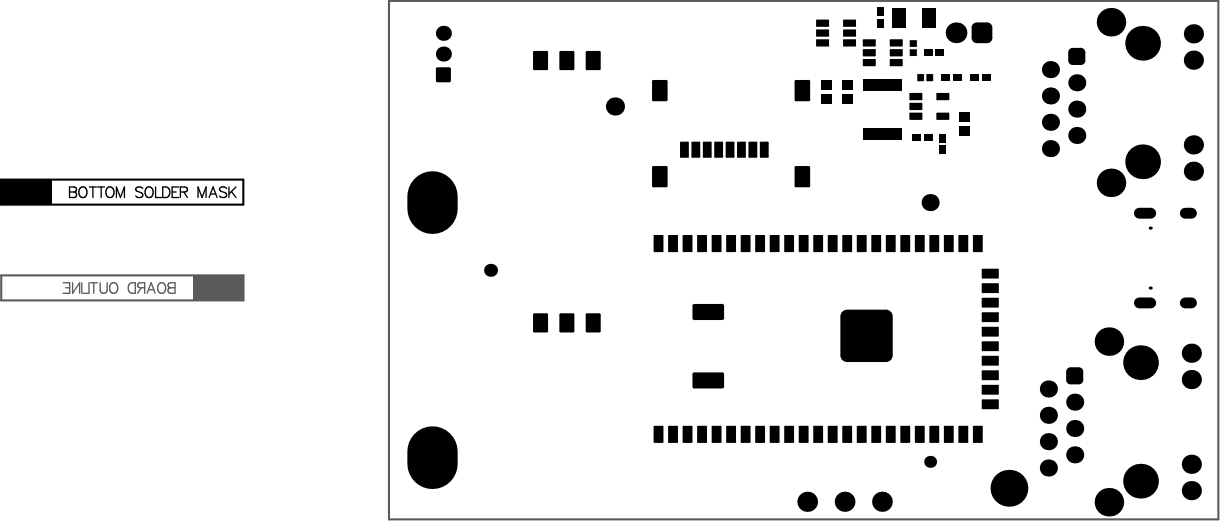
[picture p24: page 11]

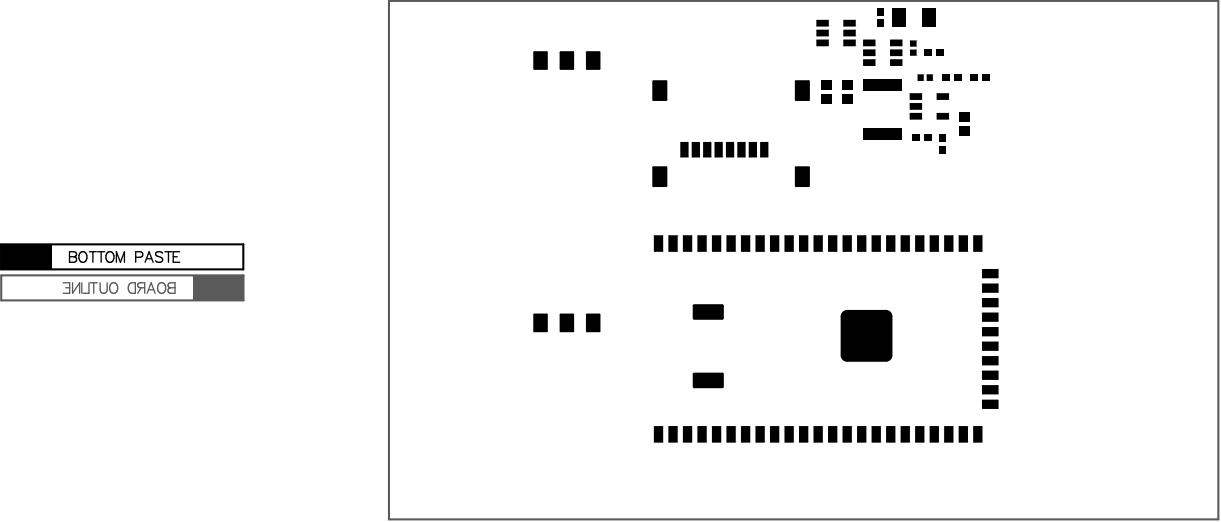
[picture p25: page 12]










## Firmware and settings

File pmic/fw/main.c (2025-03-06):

#include "ch32v003fun.h"
#include "i2c_slave.h"
#include "ws2812.h"
#include <stdio.h>
#include <string.h>

#define BTN_PIN 3
#define ENA_PIN 4
#define TP4056_CHRG_PIN 5
#define TP4056_STDBY_PIN 6
#define LTE_LED_PIN 1
#define BAT_LOW_SH_TIME 10
#define BAT_LOW_ADC_THRESH 560
#define ADC_MEAS_INT 5000
#define BTN_LED_COUNTER 1000

#define I2C_DEV_ADDR 9

#define I2C_REG_TM        4
#define I2C_REG_LED_R     8
#define I2C_REG_LED_G     9
#define I2C_REG_LED_B    10
#define I2C_REG_LED_UPD  11
#define I2C_REG_ADC      12
#define I2C_REG_IN_STATE 14
#define I2C_REG_UID      16
#define I2C_REG_OFF      31

typedef struct in_state
{
    uint8_t charge : 1;
    uint8_t stdby : 1;
    uint8_t lte : 1;
    uint8_t pwr : 1;
    uint8_t bat_low : 1;
    uint8_t : 3;
} in_state_t;

static uint8_t i2c_registers[32] = {0x00};

void onWrite(uint8_t reg, uint8_t length)
{
    funDigitalWrite(PA2, i2c_registers[0] & 1);
    if ((i2c_registers[I2C_REG_OFF] & 0xff) == 0xff) {
        GPIOD->OUTDR &= ~(1 << ENA_PIN);
    }
}

uint32_t WS2812BLEDCallback(int ledno)
{
    return (i2c_registers[10]) | (i2c_registers[9] << 8) | (i2c_registers[8] << 16);
}

static void adc_init(void)
{
    RCC->CFGR0 &= ~(0x1F << 11);
    RCC->APB2PCENR |= RCC_APB2Periph_GPIOD | RCC_APB2Periph_ADC1;
    GPIOA->CFGLR &= ~(0xf << (4 * 2));
    RCC->APB2PRSTR |= RCC_APB2Periph_ADC1;
    RCC->APB2PRSTR &= ~RCC_APB2Periph_ADC1;
    ADC1->RSQR1 = 0;
    ADC1->RSQR2 = 0;
    ADC1->RSQR3 = 0;
    ADC1->SAMPTR2 &= ~(ADC_SMP0 << (3 * 0));
    ADC1->SAMPTR2 |= 7 << (3 * 0);
    ADC1->CTLR2 |= ADC_ADON | ADC_EXTSEL;
    ADC1->CTLR2 |= ADC_RSTCAL;
    while (ADC1->CTLR2 & ADC_RSTCAL)
        ;

    ADC1->CTLR2 |= ADC_CAL;
    while (ADC1->CTLR2 & ADC_CAL)
        ;
}

uint16_t adc_get(void)
{
    ADC1->CTLR2 |= ADC_SWSTART;
    while (!(ADC1->STATR & ADC_EOC))
        ;
    return ADC1->RDATAR;
}

int main()
{
    SystemInit();
    funGpioInitAll();

    // Enable GPIOs
    RCC->APB2PCENR |= RCC_APB2Periph_GPIOD | RCC_APB2Periph_GPIOC;

    GPIOD->CFGLR &= ~(0xf << (4 * BTN_PIN));
    GPIOD->CFGLR |= (GPIO_Speed_In | GPIO_CNF_IN_PUPD) << (4 * BTN_PIN);
    GPIOD->OUTDR |= (1 << BTN_PIN);

    GPIOD->CFGLR &= ~(0xf << (4 * TP4056_CHRG_PIN));
    GPIOD->CFGLR |= (GPIO_Speed_In | GPIO_CNF_IN_PUPD) << (4 * TP4056_CHRG_PIN);
    GPIOD->OUTDR |= (1 << TP4056_CHRG_PIN);

    GPIOD->CFGLR &= ~(0xf << (4 * TP4056_STDBY_PIN));
    GPIOD->CFGLR |= (GPIO_Speed_In | GPIO_CNF_IN_PUPD) << (4 * TP4056_STDBY_PIN);
    GPIOD->OUTDR |= (1 << TP4056_STDBY_PIN);

    GPIOA->CFGLR &= ~(0xf << (4 * LTE_LED_PIN));
    GPIOA->CFGLR |= (GPIO_Speed_In | GPIO_CNF_IN_FLOATING) << (4 * LTE_LED_PIN);

    GPIOD->CFGLR &= ~(0xf << (4 * ENA_PIN));
    GPIOD->CFGLR |= (GPIO_Speed_10MHz | GPIO_CNF_OUT_PP) << (4 * ENA_PIN);
    WS2812BDMAInit();
    i2c_registers[I2C_REG_LED_R] = 0xff;
    i2c_registers[I2C_REG_LED_G] = 0xff;
    i2c_registers[I2C_REG_LED_B] = 0xff;
    WS2812BDMAStart(1);

    Delay_Ms(1000);
    GPIOD->OUTDR |= (1 << ENA_PIN); // Turn on dev

    funPinMode(PA2, GPIO_CFGLR_OUT_10Mhz_PP);    // LED
    funPinMode(PC1, GPIO_CFGLR_OUT_10Mhz_AF_OD); // SDA
    funPinMode(PC2, GPIO_CFGLR_OUT_10Mhz_AF_OD); // SCL

    SetupI2CSlave(I2C_DEV_ADDR, i2c_registers,
                  sizeof(i2c_registers), onWrite, NULL, false);

    adc_init();

    uint32_t *tm_reg = (uint32_t *)&i2c_registers[I2C_REG_TM];
    while ((GPIOD->INDR & (1 << BTN_PIN)) == 0) {
        if ((*tm_reg % ADC_MEAS_INT) >= 1000) {
            i2c_registers[I2C_REG_LED_R] = 0x40;
            i2c_registers[I2C_REG_LED_G] = 0x00;
            i2c_registers[I2C_REG_LED_B] = 0x40;
            WS2812BDMAStart(1);
        }
        Delay_Ms(50);
        (*tm_reg) += 50;
    }

    memset(i2c_registers, 0, sizeof(i2c_registers));
    memcpy(&i2c_registers[I2C_REG_UID], (uint8_t*) &ESIG->UID0, sizeof(uint32_t) * 3);
    i2c_registers[I2C_REG_LED_R] = 0x30;
    i2c_registers[I2C_REG_LED_G] = 0x20;
    i2c_registers[I2C_REG_LED_B] = 0x10;
    i2c_registers[I2C_REG_LED_UPD] = 1;
    printf("Started! \r\n");
    uint8_t low_voltage_counter = BAT_LOW_SH_TIME;

    while (1) {
        in_state_t *in_state = (in_state_t *)&i2c_registers[I2C_REG_IN_STATE];

        if (i2c_registers[I2C_REG_LED_UPD] > 0) {
            printf("Update color \r\n");
            WS2812BDMAStart(1);
            i2c_registers[I2C_REG_LED_UPD] = 0;
        } else if ((*tm_reg % ADC_MEAS_INT) == 0) {
            uint16_t *val = ((uint16_t *)&i2c_registers[I2C_REG_ADC]);
            *val = adc_get();
            printf("Measure voltage: %d \r\n", *val);

            if (*val < BAT_LOW_ADC_THRESH) {
                low_voltage_counter -= 1;
                in_state->bat_low = 1;
                printf("Device will shutdown in: %d sec \r\n",
                       (low_voltage_counter * ADC_MEAS_INT) / 1000);
                if (low_voltage_counter == 0) {
                    GPIOD->OUTDR &= ~(1 << ENA_PIN);
                }
            } else {
                low_voltage_counter = BAT_LOW_SH_TIME;
            }
        } else {
            Delay_Ms(1);
        }

        in_state->charge = (GPIOD->INDR & (1 << TP4056_CHRG_PIN)) > 0;
        in_state->stdby = (GPIOD->INDR & (1 << TP4056_STDBY_PIN)) > 0;
        in_state->lte = (GPIOA->INDR & (1 << LTE_LED_PIN)) > 0;
        in_state->pwr = (GPIOD->INDR & (1 << BTN_PIN)) > 0;

        (*tm_reg) += 1;
    }
}

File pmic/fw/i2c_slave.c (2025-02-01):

#include "ch32v003fun.h"
#include "i2c_slave.h"
#include <stdio.h>
#include <stdint.h>
#include <stdbool.h>

struct _i2c_slave_state {
    uint8_t first_write;
    uint8_t offset;
    uint8_t position;
    volatile uint8_t* volatile registers1;
    uint8_t size1;
    volatile uint8_t* volatile registers2;
    uint8_t size2;
    i2c_write_callback_t write_callback1;
    i2c_read_callback_t read_callback1;
    bool read_only1;
    i2c_write_callback_t write_callback2;
    i2c_read_callback_t read_callback2;
    bool read_only2;
    bool writing;
    bool address2matched;
} i2c_slave_state;

void SetupI2CSlave(uint8_t address, volatile uint8_t* registers, uint8_t size, i2c_write_callback_t write_callback, i2c_read_callback_t read_callback, bool read_only) {
    i2c_slave_state.first_write = 1;
    i2c_slave_state.offset = 0;
    i2c_slave_state.position = 0;
    i2c_slave_state.registers1 = registers;
    i2c_slave_state.size1 = size;
    i2c_slave_state.registers2 = NULL;
    i2c_slave_state.size2 = 0;
    i2c_slave_state.write_callback1 = write_callback;
    i2c_slave_state.read_callback1 = read_callback;
    i2c_slave_state.read_only1 = read_only;
    i2c_slave_state.write_callback2 = NULL;
    i2c_slave_state.read_callback2 = NULL;
    i2c_slave_state.read_only2 = false;

    // Enable I2C1
    RCC->APB1PCENR |= RCC_APB1Periph_I2C1;

    // Reset I2C1 to init all regs
    RCC->APB1PRSTR |= RCC_APB1Periph_I2C1;
    RCC->APB1PRSTR &= ~RCC_APB1Periph_I2C1;

    I2C1->CTLR1 |= I2C_CTLR1_SWRST;
    I2C1->CTLR1 &= ~I2C_CTLR1_SWRST;

    // Set module clock frequency
    uint32_t prerate = 2000000; // I2C Logic clock rate, must be higher than the bus clock rate
    I2C1->CTLR2 |= (FUNCONF_SYSTEM_CORE_CLOCK/prerate) & I2C_CTLR2_FREQ;

    // Enable interrupts
    I2C1->CTLR2 |= I2C_CTLR2_ITBUFEN | I2C_CTLR2_ITEVTEN | I2C_CTLR2_ITERREN;

    NVIC_EnableIRQ(I2C1_EV_IRQn); // Event interrupt
    NVIC_SetPriority(I2C1_EV_IRQn, 2 << 4);
    NVIC_EnableIRQ(I2C1_ER_IRQn); // Error interrupt
    NVIC_SetPriority(I2C1_ER_IRQn, 2 << 4);

    // Set clock configuration
    uint32_t clockrate = 1000000; // I2C Bus clock rate, must be lower than the logic clock rate
    I2C1->CKCFGR = ((FUNCONF_SYSTEM_CORE_CLOCK/(3*clockrate))&I2C_CKCFGR_CCR) | I2C_CKCFGR_FS; // Fast mode 33% duty cycle
    //I2C1->CKCFGR = ((FUNCONF_SYSTEM_CORE_CLOCK/(25*clockrate))&I2C_CKCFGR_CCR) | I2C_CKCFGR_DUTY | I2C_CKCFGR_FS; // Fast mode 36% duty cycle
    //I2C1->CKCFGR = (FUNCONF_SYSTEM_CORE_CLOCK/(2*clockrate))&I2C_CKCFGR_CCR; // Standard mode good to 100kHz

    // Set I2C address
    I2C1->OADDR1 = address << 1;
    I2C1->OADDR2 = 0;

    // Enable I2C
    I2C1->CTLR1 |= I2C_CTLR1_PE;

    // Acknowledge bytes when they are received
    I2C1->CTLR1 |= I2C_CTLR1_ACK;
}

void SetupSecondaryI2CSlave(uint8_t address, volatile uint8_t* registers, uint8_t size, i2c_write_callback_t write_callback, i2c_read_callback_t read_callback, bool read_only) {
    if (address > 0) {
        I2C1->OADDR2 = (address << 1) | 1;
        i2c_slave_state.registers2 = registers;
        i2c_slave_state.size2 = size;
        i2c_slave_state.write_callback2 = write_callback;
        i2c_slave_state.read_callback2 = read_callback;
        i2c_slave_state.read_only2 = read_only;
    } else {
        I2C1->OADDR2 = 0;
    }
}

void SetI2CSlaveReadOnly(bool read_only) {
    i2c_slave_state.read_only1 = read_only;
}

void SetSecondaryI2CSlaveReadOnly(bool read_only) {
    i2c_slave_state.read_only2 = read_only;
}

void I2C1_EV_IRQHandler(void) __attribute__((interrupt));
void I2C1_EV_IRQHandler(void) {
    uint16_t STAR1, STAR2 __attribute__((unused));
    STAR1 = I2C1->STAR1;
    STAR2 = I2C1->STAR2;

    if (STAR1 & I2C_STAR1_ADDR) { // Start event
        i2c_slave_state.first_write = 1; // Next write will be the offset
        i2c_slave_state.position = i2c_slave_state.offset; // Reset position
        i2c_slave_state.address2matched = !!(STAR2 & I2C_STAR2_DUALF);
    }

    if (STAR1 & I2C_STAR1_RXNE) { // Write event
        if (i2c_slave_state.first_write) { // First byte written, set the offset
            i2c_slave_state.offset = I2C1->DATAR;
            i2c_slave_state.position = i2c_slave_state.offset;
            i2c_slave_state.first_write = 0;
            i2c_slave_state.writing = false;
        } else { // Normal register write
            i2c_slave_state.writing = true;
            if (i2c_slave_state.address2matched) {
                if ((i2c_slave_state.registers2 != NULL) && (i2c_slave_state.position < i2c_slave_state.size2) && (!i2c_slave_state.read_only2)) {
                    i2c_slave_state.registers2[i2c_slave_state.position] = I2C1->DATAR;
                    i2c_slave_state.position++;
                }
            } else {
                if ((i2c_slave_state.registers1 != NULL) && (i2c_slave_state.position < i2c_slave_state.size1) && (!i2c_slave_state.read_only1)) {
                    i2c_slave_state.registers1[i2c_slave_state.position] = I2C1->DATAR;
                    i2c_slave_state.position++;
                }
            }
        }
    }

    if (STAR1 & I2C_STAR1_TXE) { // Read event
        i2c_slave_state.writing = false;
        if (i2c_slave_state.address2matched) {
            if ((i2c_slave_state.registers2 != NULL) && (i2c_slave_state.position < i2c_slave_state.size2)) {
                I2C1->DATAR = i2c_slave_state.registers2[i2c_slave_state.position];
                if (i2c_slave_state.read_callback2 != NULL) {
                    i2c_slave_state.read_callback2(i2c_slave_state.position);
                }
                i2c_slave_state.position++;
            } else {
                I2C1->DATAR = 0xde;
            }
        } else {
            if ((i2c_slave_state.registers1 != NULL) && (i2c_slave_state.position < i2c_slave_state.size1)) {
                I2C1->DATAR = i2c_slave_state.registers1[i2c_slave_state.position];
                if (i2c_slave_state.read_callback1 != NULL) {
                    i2c_slave_state.read_callback1(i2c_slave_state.position);
                }
                i2c_slave_state.position++;
            } else {
                I2C1->DATAR = 0xca;
            }
        }
    }

    if (STAR1 & I2C_STAR1_STOPF) { // Stop event
        I2C1->CTLR1 &= ~(I2C_CTLR1_STOP); // Clear stop
        if (i2c_slave_state.address2matched) {
            if (i2c_slave_state.write_callback2 != NULL) {
                i2c_slave_state.write_callback2(i2c_slave_state.offset, i2c_slave_state.position - i2c_slave_state.offset);
            }
        } else {
            if (i2c_slave_state.write_callback1 != NULL) {
                i2c_slave_state.write_callback1(i2c_slave_state.offset, i2c_slave_state.position - i2c_slave_state.offset);
            }
        }
    }
}
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

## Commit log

2025-02-01 initial v2
    [BOM_Price_Template_3column.xls, Bill of Materials JLCPCB-lte-router.xlsx, Bill of Materials JLCPCB-lte-router_V2.xlsx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]
2025-03-06 Fix colors, update configs, upload asterisk configs, add readme, add case stl's
    [lte-router-bat.stl, lte-router-btn.stl, lte-router-main-sma.stl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]
2025-03-06 adds a first patch, add pcb image
2025-03-18 update schematic, add some docs, fix led colors
    [BOM_Price_Template_3column.xls, Bill of Materials JLCPCB-lte-router_V2.xlsx, Bill of Materials JLCPCB-lte-router_V3.xlsx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]
2025-04-13 better handling charging mode, pmicctrl read adds status description
